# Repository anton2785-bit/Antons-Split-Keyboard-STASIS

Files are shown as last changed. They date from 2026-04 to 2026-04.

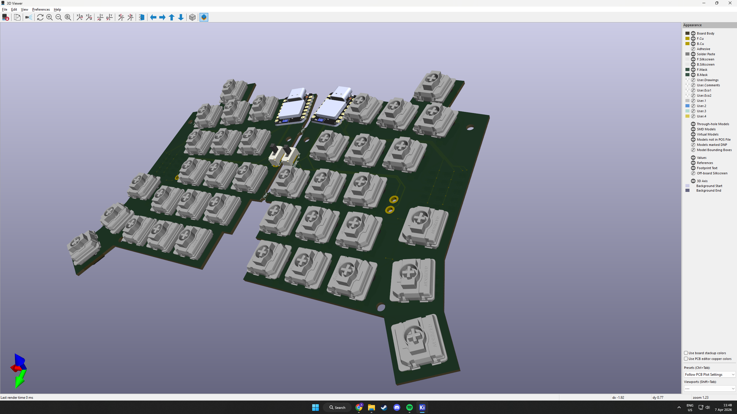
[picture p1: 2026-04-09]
Images/3D assembly.png

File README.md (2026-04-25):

# Antons-Split-Keyboard-STASIS
---
## What is this project
* This is a split keyboard. That means that it has 2 separarate parts   that are conected to the PC via bluethooth. This allows them to have separate layouts and to have the opportunity to be in different places whiie typing. 
---
## Why i made this project/split keyboard

* I wanted to have a small portable keyboard that I can still use for typing and to be compact. 
---
  ## Images
  * This is an image of the schematic:
  * Schematic left_right

  * This is the PCB:
  * PCB

  * The 3D model of the PCB:
  * 3D assembly
  * The case with half of the keyboard:
  * Case with half of the keyboard

  ---
  
  ## Assembly

* First I need to soulder everything to the PCB
* Then I need to upload a test code that will let me see what switch is what signals.
* Before it being done you need to put the now done assembly into the case. 
* After that I upload the real code and I am happy to use it afterwards.
  
  ---
  
 ## BOM
| Component | Purpose | Qty | Unit Cost | Total | Distributor |
|---|---|-----|---|---|---|
| [Keycaps](https://www.aliexpress.com/item/1005010519485476.html) | Low-profile keycaps | 1 set | — | $16.68 | AliExpress |
| [Resistors](https://www.aliexpress.com/item/1005010519485476.html) | Battery voltage divider (806kΩ + 1MΩ) | 1 set | — | $4.32 | AliExpress |
| [Gateron Hotswap Sockets](https://www.gateron.com/products/gateron-low-profile-switch-hot-swap-pcb-socket?VariantsId=10234) | Low-profile hotswap | 1 set | — | $7.00 | Gateron |
| [Gateron KS-33 Switches](https://www.gateron.com/products/gateron-ks-33-low-profile-20-banana-switch?VariantsId=10734) | Low-profile banana switches | 2 sets | — | $19.60 | Gateron |
| [PCB](https://jlcpcb.com) | Reversible split PCB (JLCPCB) | 1 set | — | $35.00 | JLCPCB |
| [Seeed XIAO nRF52840](https://www.seeedstudio.com/Seeed-XIAO-BLE-nRF52840-p-5201.html) | Wireless MCU, one per half | 2 | $17.00 | $34.00 | Seeed Studio |

---
## Credits

* Designed and built by *(Anton/ Anton-2785-bit)
* Inspired by open‑source mechanical keyboard and hackpad communities (https://stasis.hackclub.com/dashboard).

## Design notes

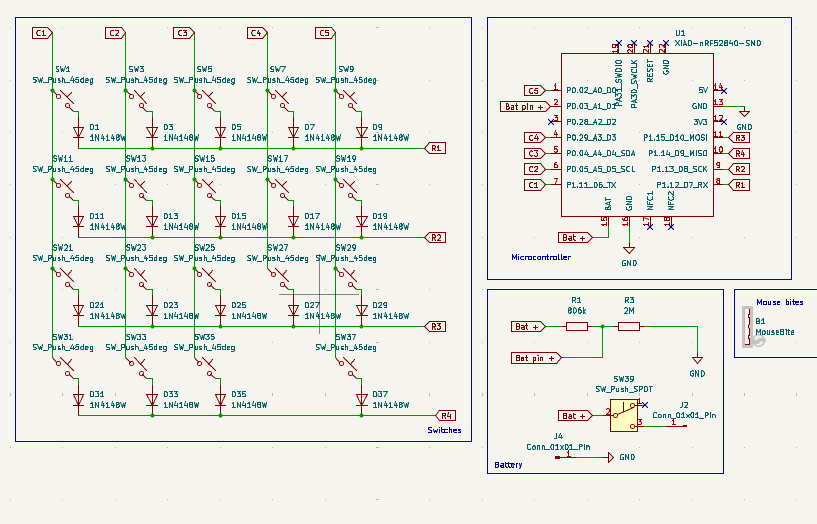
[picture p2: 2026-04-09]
Images/Schematic left_right.png

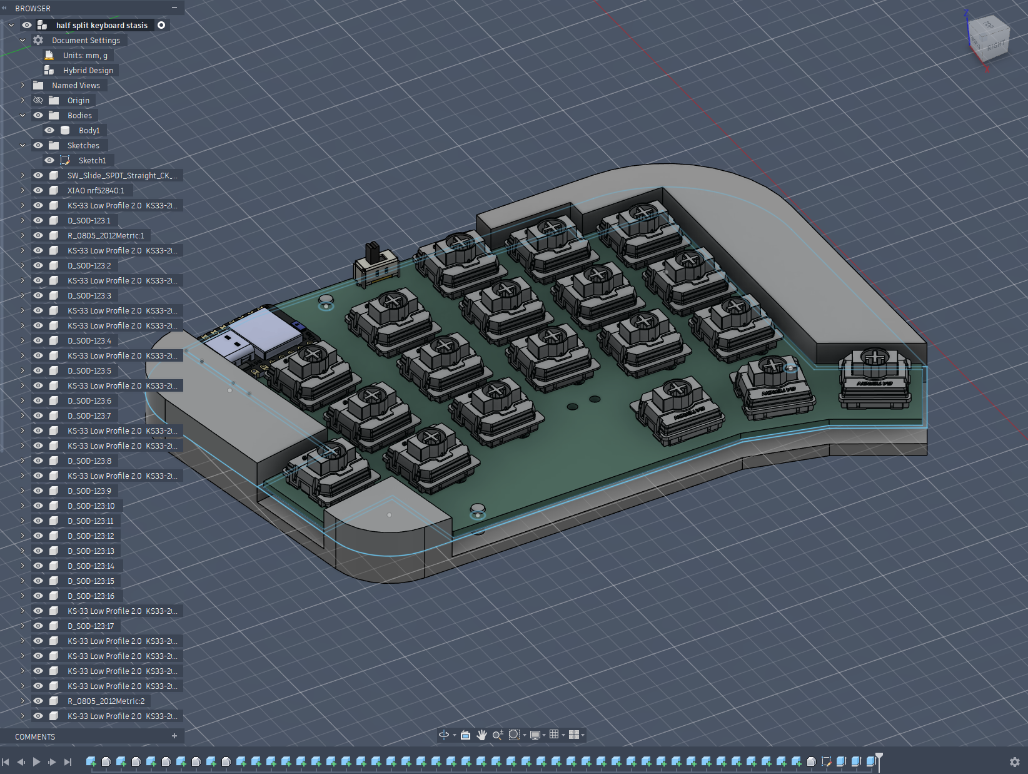
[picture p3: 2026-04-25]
Images/Case with half of the keyboard.png

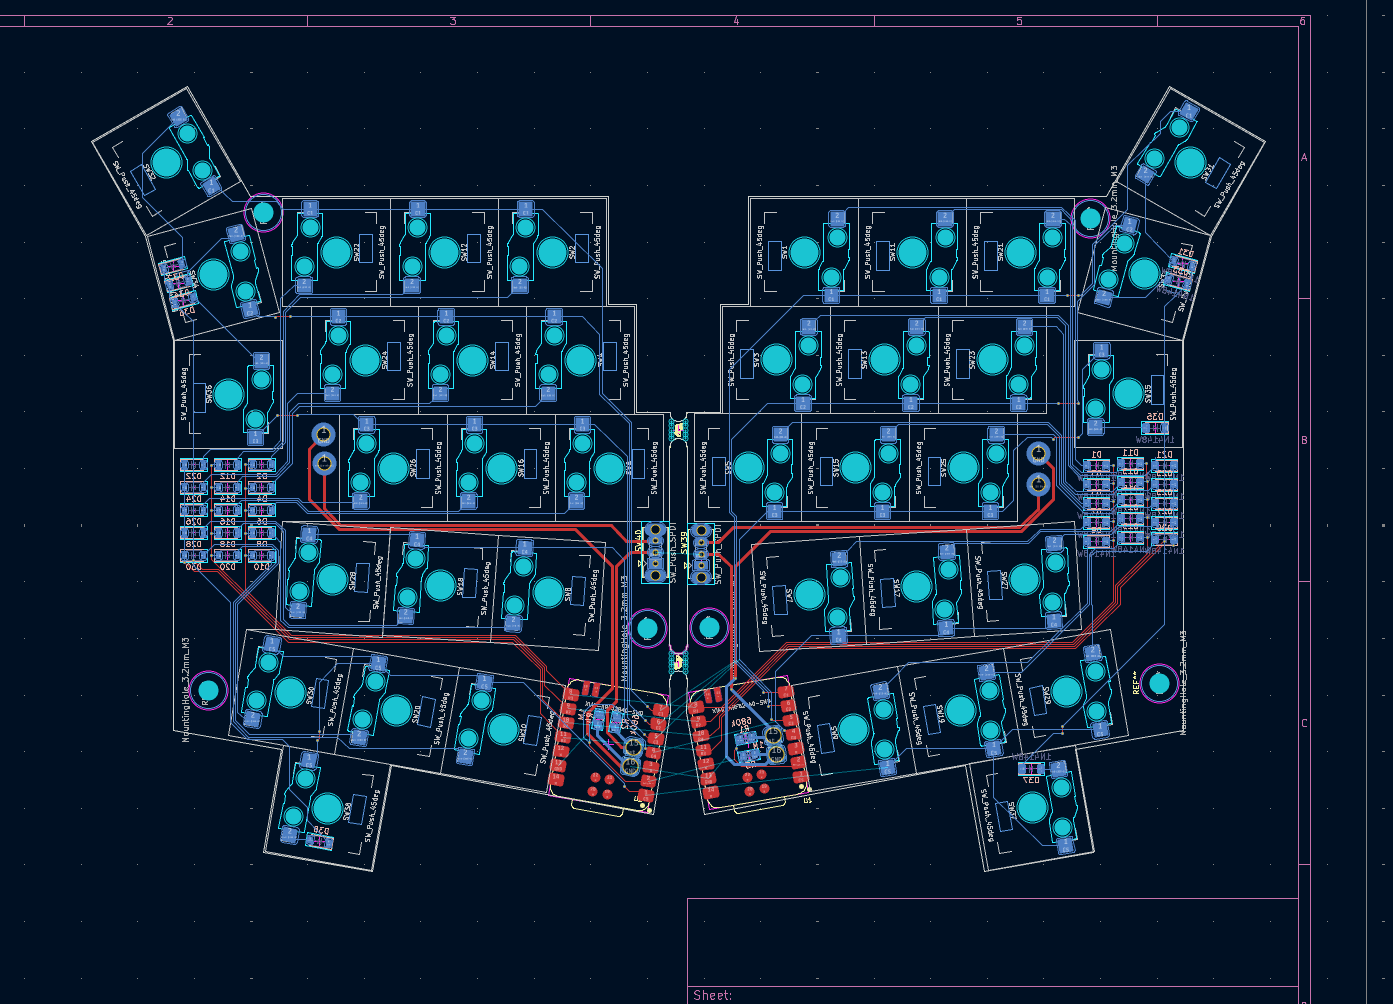
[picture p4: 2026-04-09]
Images/PCB.png

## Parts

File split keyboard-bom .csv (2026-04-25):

Name | Purpose | Quantity | Total Cost (USD) | Link | Distributor
keycaps | makes the typing experience better | 1 | 16.68 | https://www.aliexpress.com/item/1005010519485476.html?mp=1 | Aliexpress
resistors | resists | 1 | 4.32 | https://www.aliexpress.com/item/1005010519485476.html?mp=1 | Aliexpress
gateron hotswap modules | Making the switches hotswapable | 1 | 7.00 | https://www.gateron.com/products/gateron-low-profile-switch-hot-swap-pcb-socket?VariantsId=10234 | Gateron
gateron switches | pushing buttons | 2 | 19.60 | https://www.gateron.com/products/gateron-ks-33-low-profile-20-banana-switch?VariantsId=10734 | Gateron
PCB | The place to soulder/hold everything | 1 | 35.00 |  | JLCPCB
Seed Studio XIAO nrf52840 | The brain | 2 | 34.00 | https://www.seeedstudio.com/Seeed-XIAO-BLE-nRF52840-p-5201.html | Seed Studio

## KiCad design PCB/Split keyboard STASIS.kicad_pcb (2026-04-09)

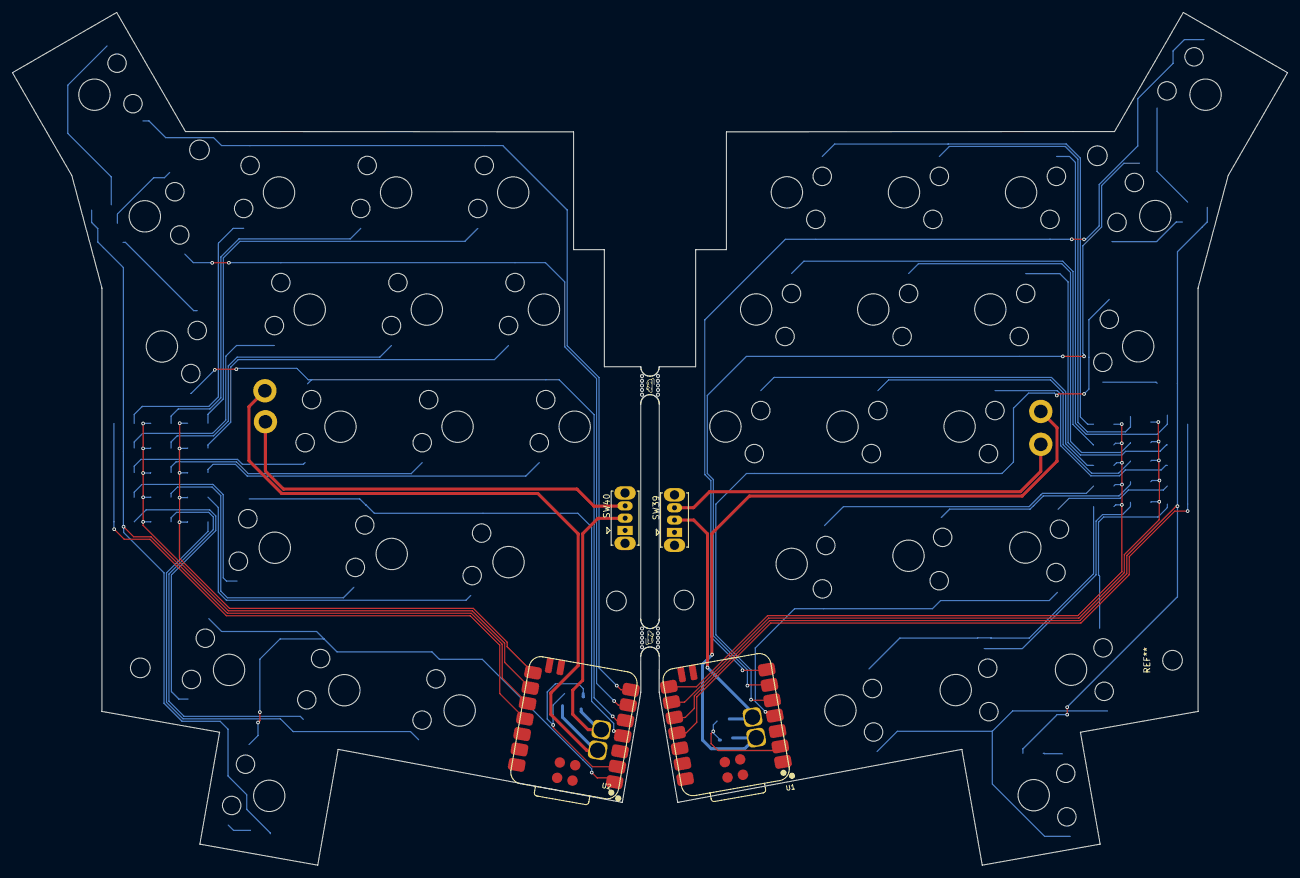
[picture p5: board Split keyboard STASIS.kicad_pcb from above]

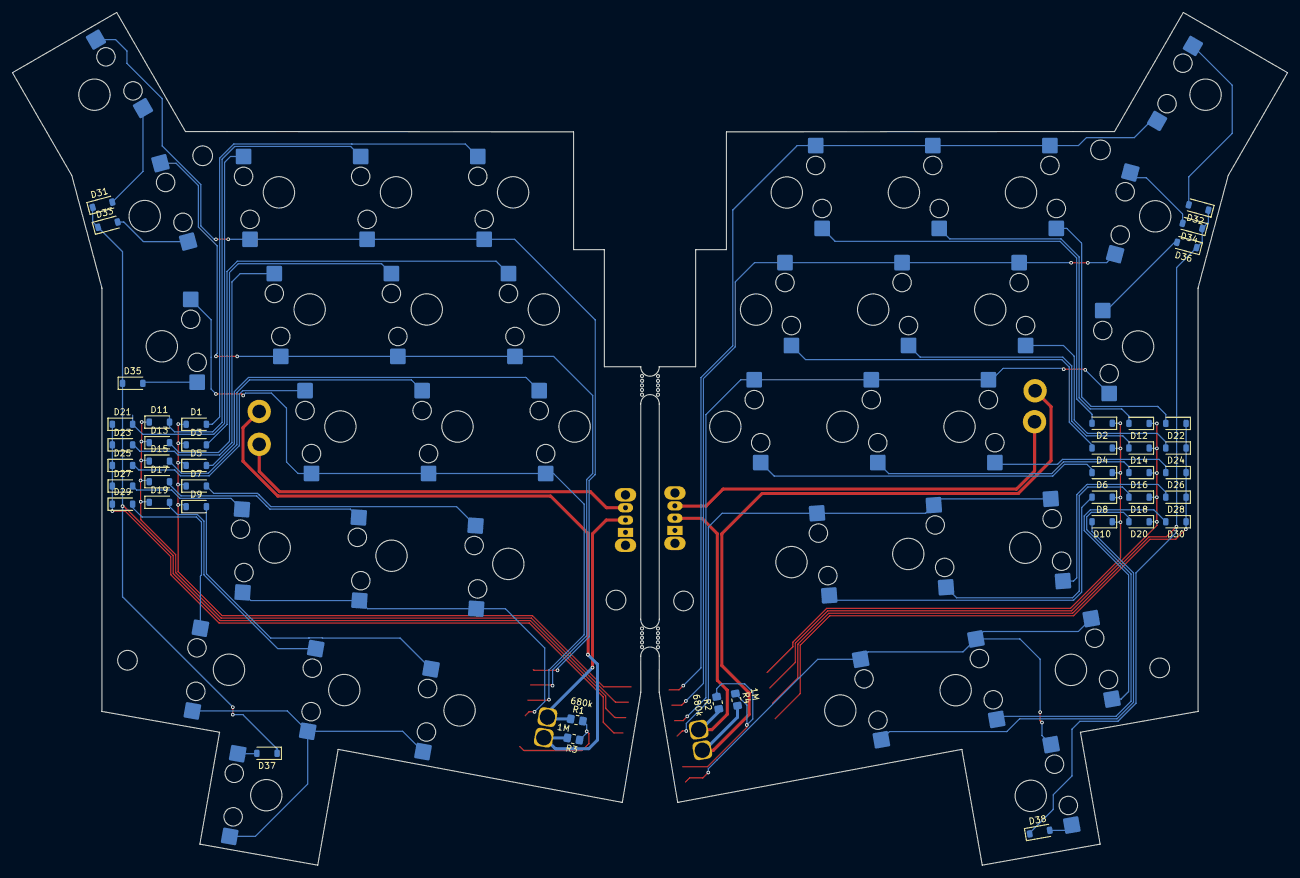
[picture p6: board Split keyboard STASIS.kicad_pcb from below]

Board: 2 copper layers, 207.4 x 138.7 mm, 90 parts (80 on the bottom side), 52 nets.

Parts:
B1, B2: MouseBite; mouse-bite-3mm-6mm
D1, D2, D3, D4, D5, D6, D7, D8, D9, D10, D11, D12, D13, D14, D15, D16, D17, D18, D19, D20, D21, D22, D23, D24, D25, D26, D27, D28, D29, D30, D31, D32, D33, D34, D35, D36, D37, D38: 1N4148W; D_SOD-123
J1, J2, J3, J4: Conn_01x01_Pin; MountingHole_2.2mm_M2_DIN965_Pad
R1, R2: 680k; R_0805_2012Metric_Pad1.20x1.40mm_HandSolder
R3, R4: 1M; R_0805_2012Metric_Pad1.20x1.40mm_HandSolder
SW1, SW2, SW3, SW4, SW5, SW6, SW7, SW8, SW9, SW10, SW11, SW12, SW13, SW14, SW15, SW16, SW17, SW18, SW19, SW20, SW21, SW22, SW23, SW24, SW25, SW26, SW27, SW28, SW29, SW30, SW31, SW32, SW33, SW34, SW35, SW36, SW37, SW38: SW_Push_45deg; Gateron-KS33-Hotswap-1U
SW39, SW40: SW_Push_SPDT; SW_Slide_SPDT_Straight_CK_OS102011MS2Q
U1, U2: XIAO-nRF52840-SMD; modified-XIAO-nRF52840-SMD

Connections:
Bat +: R1.1, R2.1, SW39.2 (B), SW40.2 (B), U1.15 (BAT), U2.15 (BAT)
Bat pin +: R1.2, R2.2, R3.1, R4.1, U1.2 (P0.03_A1_D1), U2.2 (P0.03_A1_D1)
C1: SW1.1, SW2.1, SW11.1, SW12.1, SW21.1, SW22.1, SW31.1, SW32.1, U1.7 (P1.11_D6_TX), U2.7 (P1.11_D6_TX)
C2: SW3.1, SW4.1, SW13.1, SW14.1, SW23.1, SW24.1, SW33.1, SW34.1, U1.6 (P0.05_A5_D5_SCL), U2.6 (P0.05_A5_D5_SCL)
C3: SW5.1, SW6.1, SW15.1, SW16.1, SW25.1, SW26.1, SW35.1, SW36.1, U1.5 (P0.04_A4_D4_SDA), U2.5 (P0.04_A4_D4_SDA)
C4: SW7.1, SW8.1, SW17.1, SW18.1, SW27.1, SW28.1, U1.4 (P0.29_A3_D3), U2.4 (P0.29_A3_D3)
C5: SW9.1, SW10.1, SW19.1, SW20.1, SW29.1, SW30.1, SW37.1, SW38.1, U1.1 (P0.02_A0_D0), U2.1 (P0.02_A0_D0)
GND: J3.1, J4.1, R3.2, R4.2, U1.13 (GND), U1.16 (GND), U2.13 (GND), U2.16 (GND)
unnamed: D1.2 (A), SW1.2
unnamed: D2.2 (A), SW2.2
unnamed: D3.2 (A), SW3.2
unnamed: D4.2 (A), SW4.2
unnamed: D5.2 (A), SW5.2
unnamed: D6.2 (A), SW6.2
unnamed: D7.2 (A), SW7.2
unnamed: D8.2 (A), SW8.2
unnamed: D9.2 (A), SW9.2
unnamed: D10.2 (A), SW10.2
unnamed: D11.2 (A), SW11.2
unnamed: D12.2 (A), SW12.2
unnamed: D13.2 (A), SW13.2
unnamed: D14.2 (A), SW14.2
unnamed: D15.2 (A), SW15.2
unnamed: D16.2 (A), SW16.2
unnamed: D17.2 (A), SW17.2
unnamed: D18.2 (A), SW18.2
unnamed: D19.2 (A), SW19.2
unnamed: D20.2 (A), SW20.2
unnamed: D21.2 (A), SW21.2
unnamed: D22.2 (A), SW22.2
unnamed: D23.2 (A), SW23.2
unnamed: D24.2 (A), SW24.2
unnamed: D25.2 (A), SW25.2
unnamed: D26.2 (A), SW26.2
unnamed: D27.2 (A), SW27.2
unnamed: D28.2 (A), SW28.2
unnamed: D29.2 (A), SW29.2
unnamed: D30.2 (A), SW30.2
unnamed: D31.2 (A), SW31.2
unnamed: D32.2 (A), SW32.2
unnamed: D33.2 (A), SW33.2
unnamed: D34.2 (A), SW34.2
unnamed: D35.2 (A), SW35.2
unnamed: D36.2 (A), SW36.2
unnamed: D37.2 (A), SW37.2
unnamed: D38.2 (A), SW38.2
unnamed: J1.1, SW40.3 (C)
unnamed: J2.1, SW39.3 (C)
R1: D1.1 (K), D2.1 (K), D3.1 (K), D4.1 (K), D5.1 (K), D6.1 (K), D7.1 (K), D8.1 (K), D9.1 (K), D10.1 (K), U1.8 (P1.12_D7_RX), U2.8 (P1.12_D7_RX)
R2: D11.1 (K), D12.1 (K), D13.1 (K), D14.1 (K), D15.1 (K), D16.1 (K), D17.1 (K), D18.1 (K), D19.1 (K), D20.1 (K), U1.9 (P1.13_D8_SCK), U2.9 (P1.13_D8_SCK)
R3: D21.1 (K), D22.1 (K), D23.1 (K), D24.1 (K), D25.1 (K), D26.1 (K), D27.1 (K), D28.1 (K), D29.1 (K), D30.1 (K), U1.11 (P1.15_D10_MOSI), U2.11 (P1.15_D10_MOSI)
R4: D31.1 (K), D32.1 (K), D33.1 (K), D34.1 (K), D35.1 (K), D36.1 (K), D37.1 (K), D38.1 (K), U1.10 (P1.14_D9_MISO), U2.10 (P1.14_D9_MISO)

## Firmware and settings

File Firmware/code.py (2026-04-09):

"""
SplitKey38 — CircuitPython firmware
Left half (USB host side)

Hardware:  Seeed XIAO nRF52840
Matrix:    5 cols × 4 rows, COL2ROW diodes (1N4148W)
Split:     UART over D7(TX) / D6(RX) between halves
USB HID:   left half plugged into PC via USB-C

Pin mapping (from schematic):
  Rows (driven LOW, input pulled HIGH):
    ROW0 → D6  / P1.11
    ROW1 → D7  / P1.12   ← also UART RX from right half
    ROW2 → D8  / P1.13
    ROW3 → D9  / P1.14   (thumb row)

  Cols (read):
    COL0 → D0  / P0.02
    COL1 → D1  / P0.03
    COL2 → D2  / P0.28
    COL3 → D3  / P0.29
    COL4 → D4  / P0.04

NOTE: If you use D6/D7 for UART, free up two other pins for ROW0/ROW1.
      Adjust ROW_PINS below to match your final PCB traces.
      UART_TX → D10 (P1.15 / MOSI) on left half
      UART_RX → D7  (P1.12)        on left half  ← conflicts with ROW1
      Recommended: use D10(TX) on left, D10(RX) on right, cross-wired.
      See WIRING NOTE at bottom of file.
"""

import board
import busio
import digitalio
import usb_hid
import time
import struct

from adafruit_hid.keyboard import Keyboard
from adafruit_hid.keyboard_layout_us import KeyboardLayoutUS
from adafruit_hid.keycode import Keycode

# ─── UART (inter-half communication) ────────────────────────────────────────
# Left half receives key events from right half over UART.
# Protocol: single byte per event — high bit = press(1)/release(0), low 7 bits = key index (0-18)
uart = busio.UART(
    tx=board.D10,   # P1.15 — to right half RX
    rx=board.D7,    # P1.12 — from right half TX
    baudrate=38400,
    timeout=0,      # non-blocking
)

# ─── MATRIX PINS ────────────────────────────────────────────────────────────
# Rows: output, driven LOW to scan
ROW_PINS = [
    board.D6,   # P1.11 — row 0 (SW1 SW3 SW6 SW7 SW9)
    board.D8,   # P1.13 — row 1 (SW11 SW13 SW15 SW17 SW19)  ← skip D7 (UART)
    board.D9,   # P1.14 — row 2 (SW21 SW23 SW25 SW27 SW29)
    board.D4,   # P0.04 — row 3 / thumb (SW31 SW33 SW35 SW37)
]

# Cols: input, pulled HIGH; LOW = key pressed
COL_PINS = [
    board.D0,   # P0.02 — col 0
    board.D1,   # P0.03 — col 1
    board.D2,   # P0.28 — col 2
    board.D3,   # P0.29 — col 3
    board.A4,   # P0.05 — col 4  (D4 used for row, use A4/D5 instead)
]

NUM_ROWS = len(ROW_PINS)
NUM_COLS = len(COL_PINS)

# ─── LAYER DEFINITIONS ──────────────────────────────────────────────────────
# Index = row * 5 + col  (left side, 0-18)
# None = transparent (falls through to BASE)
# Key index layout:
#   row0: [0][1][2][3][4]   → Tab Q W E R
#   row1: [5][6][7][8][9]   → Esc A S D F
#   row2: [10][11][12][13][14] → Sft Z X C V
#   row3: [15][16][17][18]  → Ctrl GUI Alt Spc   (thumb, col4 unused)

KC = Keycode

BASE_L = [
    # row 0
    KC.TAB,         KC.Q,       KC.W,       KC.E,       KC.R,
    # row 1
    KC.ESCAPE,      KC.A,       KC.S,       KC.D,       KC.F,
    # row 2
    KC.LEFT_SHIFT,  KC.Z,       KC.X,       KC.C,       KC.V,
    # row 3 (thumb — only 4 keys, index 15-18, col4=None)
    KC.LEFT_CONTROL, KC.LEFT_GUI, KC.LEFT_ALT, KC.SPACE,
]

NAV_L = [
    # row 0
    None, None, None, None, None,
    # row 1
    None, None, None, None, None,
    # row 2
    None, None, None, None, None,
    # row 3 (thumb)
    None, None, None, None,
]

SYM_L = [
    # row 0
    KC.GRAVE, KC.ONE,  KC.TWO,   KC.THREE, KC.FOUR,
    # row 1
    None,     KC.EXCLAMATION_POINT, KC.AT, KC.POUND, KC.DOLLAR,
    # row 2
    None,     None,    None,     None,     None,
    # row 3 (thumb)
    None,     None,    None,     None,
]

# Right half keymaps
# Key index 0-18, same row/col structure, mirrored columns
# Right row0: T Y U I O  → col order: [col4..col0] visually but wired same
BASE_R = [
    # row 0
    KC.T,           KC.Y,       KC.U,       KC.I,       KC.O,
    # row 1
    KC.G,           KC.H,       KC.J,       KC.K,       KC.L,
    # row 2
    KC.B,           KC.N,       KC.M,       KC.COMMA,   KC.PERIOD,
    # row 3 (thumb)
    KC.RETURN,      None,       None,       KC.RIGHT_SHIFT,  # MO1/MO2 handled in logic
]

NAV_R = [
    # row 0
    KC.PAGE_UP,   KC.HOME,    KC.UP_ARROW,   KC.END,        KC.DELETE,
    # row 1
    KC.PAGE_DOWN, KC.LEFT_ARROW, KC.DOWN_ARROW, KC.RIGHT_ARROW, KC.INSERT,
    # row 2
    None,         None,       None,          None,          KC.BACKSPACE,
    # row 3 (thumb)
    None,         None,       None,          None,
]

SYM_R = [
    # row 0
    KC.FIVE,      KC.SIX,     KC.SEVEN,      KC.EIGHT,      KC.NINE,
    # row 1
    KC.PERCENT,   KC.CARET,   KC.AMPERSAND,  KC.ASTERISK,   KC.ZERO,
    # row 2
    None,         KC.LEFT_BRACKET, KC.RIGHT_BRACKET, KC.MINUS, KC.EQUALS,
    # row 3 (thumb)
    None,         None,       None,          None,
]

LAYERS_L = [BASE_L, NAV_L, SYM_L]
LAYERS_R = [BASE_R, NAV_R, SYM_R]

# Right thumb key indices that activate layers
RIGHT_MO1 = 16   # MO(NAV)  — index in right keymap row3 col1
RIGHT_MO2 = 17   # MO(SYM)  — index in right keymap row3 col2

# ─── SETUP ──────────────────────────────────────────────────────────────────
rows = []
for pin in ROW_PINS:
    r = digitalio.DigitalInOut(pin)
    r.direction = digitalio.Direction.OUTPUT
    r.value = True   # idle HIGH
    rows.append(r)

cols = []
for pin in COL_PINS:
    c = digitalio.DigitalInOut(pin)
    c.direction = digitalio.Direction.INPUT
    c.pull = digitalio.Pull.UP
    cols.append(c)

kbd = Keyboard(usb_hid.devices)

# ─── STATE ──────────────────────────────────────────────────────────────────
left_state  = [False] * 19   # current pressed state, left half
right_state = [False] * 19   # received from right half over UART

prev_left  = [False] * 19
prev_right = [False] * 19

active_layer = 0

# ─── MATRIX SCAN ─────────────────────────────────────────────────────────────
def scan_matrix():
    """Returns a 19-element list of booleans — True = key pressed."""
    result = [False] * 19
    for row_idx, row in enumerate(rows):
        row.value = False   # drive LOW
        time.sleep(0.000002)  # 2µs settle
        for col_idx, col in enumerate(cols):
            if not col.value:   # LOW = pressed (COL2ROW + pull-up)
                key_idx = row_idx * NUM_COLS + col_idx
                if key_idx < 19:
                    result[key_idx] = True
        row.value = True    # restore HIGH
    return result

# ─── UART RECEIVE ────────────────────────────────────────────────────────────
def read_uart():
    """
    Reads all pending bytes from UART.
    Protocol: 1 byte per event
      bit 7 : 1 = press, 0 = release
      bits 6-0 : key index 0-18
    """
    while True:
        data = uart.read(1)
        if data is None or len(data) == 0:
            break
        byte = data[0]
        pressed  = bool(byte & 0x80)
        key_idx  = byte & 0x7F
        if 0 <= key_idx <= 18:
            right_state[key_idx] = pressed

# ─── LAYER RESOLUTION ────────────────────────────────────────────────────────
def resolve_key(keymap_list, idx):
    """Walk layers top-down, return first non-None keycode."""
    for layer in range(len(keymap_list) - 1, -1, -1):
        kc = keymap_list[layer][idx]
        if kc is not None:
            return kc
    return None

def get_active_layers():
    """Return list of active layer indices based on held MO keys."""
    layers = [0]   # base always active
    if right_state[RIGHT_MO1]:
        layers.append(1)
    if right_state[RIGHT_MO2]:
        layers.append(2)
    return layers

# ─── MAIN LOOP ───────────────────────────────────────────────────────────────
print("SplitKey38 ready")

while True:
    # 1. Read right half events from UART
    read_uart()

    # 2. Scan left half matrix
    left_state = scan_matrix()

    # 3. Determine active layers
    active_layers = get_active_layers()

    # 4. Build layered keymaps for this tick
    layered_l = [BASE_L, NAV_L, SYM_L]
    layered_r = [BASE_R, NAV_R, SYM_R]

    # 5. Process left half changes
    for i in range(19):
        if left_state[i] != prev_left[i]:
            kc = None
            # Walk layers top-down
            for layer in reversed(active_layers):
                candidate = layered_l[layer][i]
                if candidate is not None:
                    kc = candidate
                    break
            if kc is not None:
                if left_state[i]:
                    kbd.press(kc)
                else:
                    kbd.release(kc)
            prev_left[i] = left_state[i]

    # 6. Process right half changes
    for i in range(19):
        # Skip MO keys — they control layers, not HID keycodes
        if i in (RIGHT_MO1, RIGHT_MO2):
            prev_right[i] = right_state[i]
            continue
        if right_state[i] != prev_right[i]:
            kc = None
            for layer in reversed(active_layers):
                candidate = layered_r[layer][i]
                if candidate is not None:
                    kc = candidate
                    break
            if kc is not None:
                if right_state[i]:
                    kbd.press(kc)
                else:
                    kbd.release(kc)
            prev_right[i] = right_state[i]

    time.sleep(0.001)   # 1ms scan rate


# ─── WIRING NOTE ─────────────────────────────────────────────────────────────
# Left XIAO D10 (TX) ──────────────── Right XIAO D6  (RX)
# Left XIAO D7  (RX) ──────────────── Right XIAO D10 (TX)
# Left GND           ──────────────── Right GND
# No level shifter needed — both 3.3V
#
# The right half runs right_half.py (see that file).
# Only the LEFT half connects to USB.

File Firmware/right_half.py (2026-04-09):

"""
SplitKey38 — CircuitPython firmware
Right half (peripheral side)

This half does NOT connect to USB for HID.
It scans its matrix and sends key events to the left half over UART.

Protocol: 1 byte per event
  bit 7    : 1 = press, 0 = release
  bits 6-0 : key index 0-18

Pin mapping (same PCB, flipped — same physical pins):
  Rows: D6(P1.11), D8(P1.13), D9(P1.14), D4(P0.04)
  Cols: D0(P0.02), D1(P0.03), D2(P0.28), D3(P0.29), A4(P0.05)
  UART TX: D10 (P1.15) → left half RX
  UART RX: D7  (P1.12) ← left half TX (unused on right, but pin reserved)
"""

import board
import busio
import digitalio
import time

# ─── UART ────────────────────────────────────────────────────────────────────
uart = busio.UART(
    tx=board.D10,  # P1.15 → left half D7 (RX)
    rx=board.D7,   # P1.12 ← left half D10 (TX) — reserved, not used
    baudrate=38400,
    timeout=0,
)

# ─── MATRIX PINS ─────────────────────────────────────────────────────────────
ROW_PINS = [
    board.D6,   # P1.11 — row 0
    board.D8,   # P1.13 — row 1
    board.D9,   # P1.14 — row 2
    board.D4,   # P0.04 — row 3 (thumb)
]

COL_PINS = [
    board.D0,   # P0.02 — col 0
    board.D1,   # P0.03 — col 1
    board.D2,   # P0.28 — col 2
    board.D3,   # P0.29 — col 3
    board.A4,   # P0.05 — col 4
]

NUM_ROWS = len(ROW_PINS)
NUM_COLS = len(COL_PINS)

# ─── SETUP ───────────────────────────────────────────────────────────────────
rows = []
for pin in ROW_PINS:
    r = digitalio.DigitalInOut(pin)
    r.direction = digitalio.Direction.OUTPUT
    r.value = True
    rows.append(r)

cols = []
for pin in COL_PINS:
    c = digitalio.DigitalInOut(pin)
    c.direction = digitalio.Direction.INPUT
    c.pull = digitalio.Pull.UP
    cols.append(c)

# ─── STATE ───────────────────────────────────────────────────────────────────
prev_state = [False] * 19

# ─── MATRIX SCAN ─────────────────────────────────────────────────────────────
def scan_matrix():
    result = [False] * 19
    for row_idx, row in enumerate(rows):
        row.value = False
        time.sleep(0.000002)
        for col_idx, col in enumerate(cols):
            if not col.value:
                key_idx = row_idx * NUM_COLS + col_idx
                if key_idx < 19:
                    result[key_idx] = True
        row.value = True
    return result

# ─── MAIN LOOP ───────────────────────────────────────────────────────────────
print("SplitKey38 right half ready")

while True:
    current = scan_matrix()

    for i in range(19):
        if current[i] != prev_state[i]:
            # Encode: bit7 = press/release, bits 6-0 = index
            byte = (0x80 | i) if current[i] else i
            uart.write(bytes([byte]))
        prev_state[i] = current[i]

    time.sleep(0.001)
